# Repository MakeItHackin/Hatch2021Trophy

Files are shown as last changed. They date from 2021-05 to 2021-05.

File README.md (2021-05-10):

# Hatch2021Trophy
Overview of the trophies created for the HATCH 2021 Winners

Thanks for visiting this page to learn more about your HATCH trophy!

View my YouTube video for a quick overview and demo:
https://youtu.be/y4QBiJtTjaM

The trophy uses open source code and hardware, so please hack it to make it do what you want. It comes loaded with some demo code to test each of the components.

There may be updates to this page, but if you have any questions or comments, please initiate a "Issue" on github, and I will answer as soon as I can.

With the demo code loaded, the trophy will boot to the 'menu' screen.
Press the main button scroll through the menu.
When you go into the 'Demo Mode' Function, the program will loop forever. To exit the loop, just press the reset button.

The following functions are loaded with the demo software:
Lite Sense (view the analog signal from the light sensor. Minimum is ~888 (dark) and Maximum is ~1000 (very very bright))
Demo Mode (scrolls through all features, sensors, and animations)

The trophies feature the following major components:
ATTINY-85 Microcontroller
128x32 Pixel OLED display
Neopixel (WS2812v3) RGB LEDs
Light Sensor
18650 Battery, along with charging circuit (micro USB)
Pinout for all 8 pins on the microcontroller, so you can program it or add other features.

How to set up Arduino:
https://www.arduino.cc/en/Guide/ArduinoUno

How to Program the trophy (Arduino as ISP):
The trophy contains an ATTINY85 Microcontroller and can be programed unsing an arduino board, like the arduino uno.  
https://create.arduino.cc/projecthub/arjun/programming-attiny85-with-arduino-uno-afb829

Pinout for the ATTINY-85 eight-pin breakout:
-----------
| 1 2 3 4 |
| 5 6 7 8 |
-----------
PINs 1,2,3,5,6,7 are used for uploading code via ISCP to the ATTINY-85

1 - 
2 - 
3 - 
4 - 
5 - 
6 - 
7 - 
8 - 

It may be possible to program the trophy using a micro USB cable and the Micronucleus bootloader.  I have included the circuitry for that, but haven't tried to configure it.  It seems like most modern computers have trouble with it.  But if you want that functionality, give it a try!  For advanced users only.

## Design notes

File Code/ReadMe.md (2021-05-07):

The "HATCH2021TrophyCodeV1_0" is the main arduino program running the demo code.  The other files are the libraries needed for the RGB LEDs and OLED Display

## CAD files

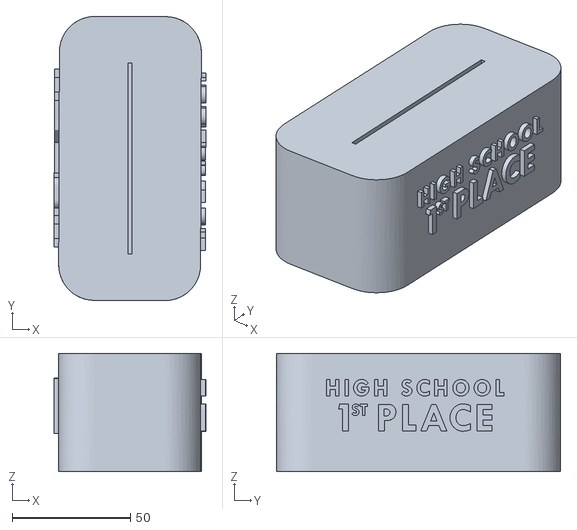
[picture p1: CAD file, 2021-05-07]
3DPrintedBases/Hatch2020TrophyBaseHS1st.stl
64.2 x 120.1 x 50.0

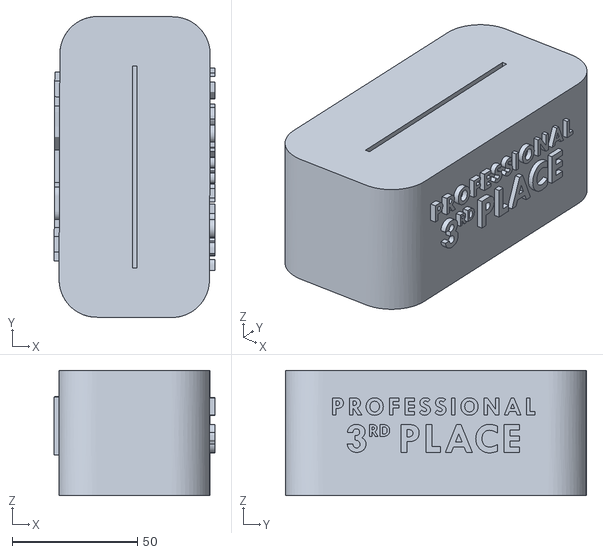
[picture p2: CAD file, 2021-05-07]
3DPrintedBases/Hatch2020TrophyBasePro3rd.stl
64.1 x 120.1 x 50.0

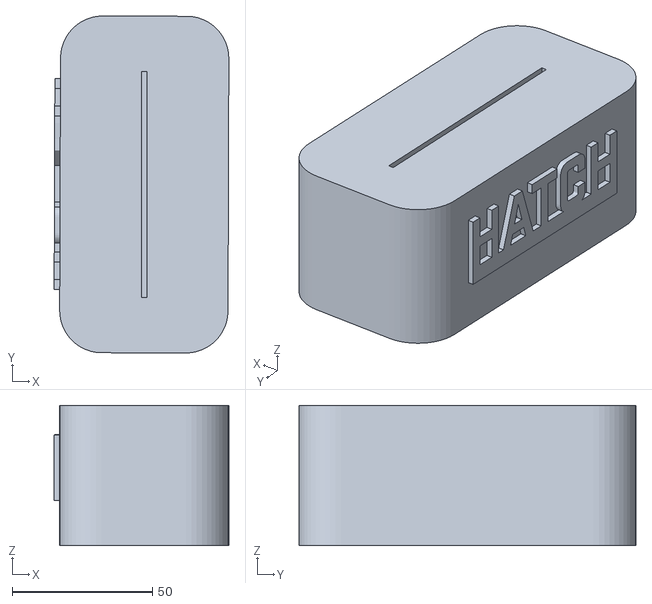
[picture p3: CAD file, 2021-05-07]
3DPrintedBases/Hatch2021TrophyBase.stl
62.3 x 120.1 x 50.0

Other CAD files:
3DPrintedBases/Hatch2020TrophyBaseHS2nd.stl
3DPrintedBases/Hatch2020TrophyBasePro2nd.stl
3DPrintedBases/Hatch2020TrophyBasePro1st.stl

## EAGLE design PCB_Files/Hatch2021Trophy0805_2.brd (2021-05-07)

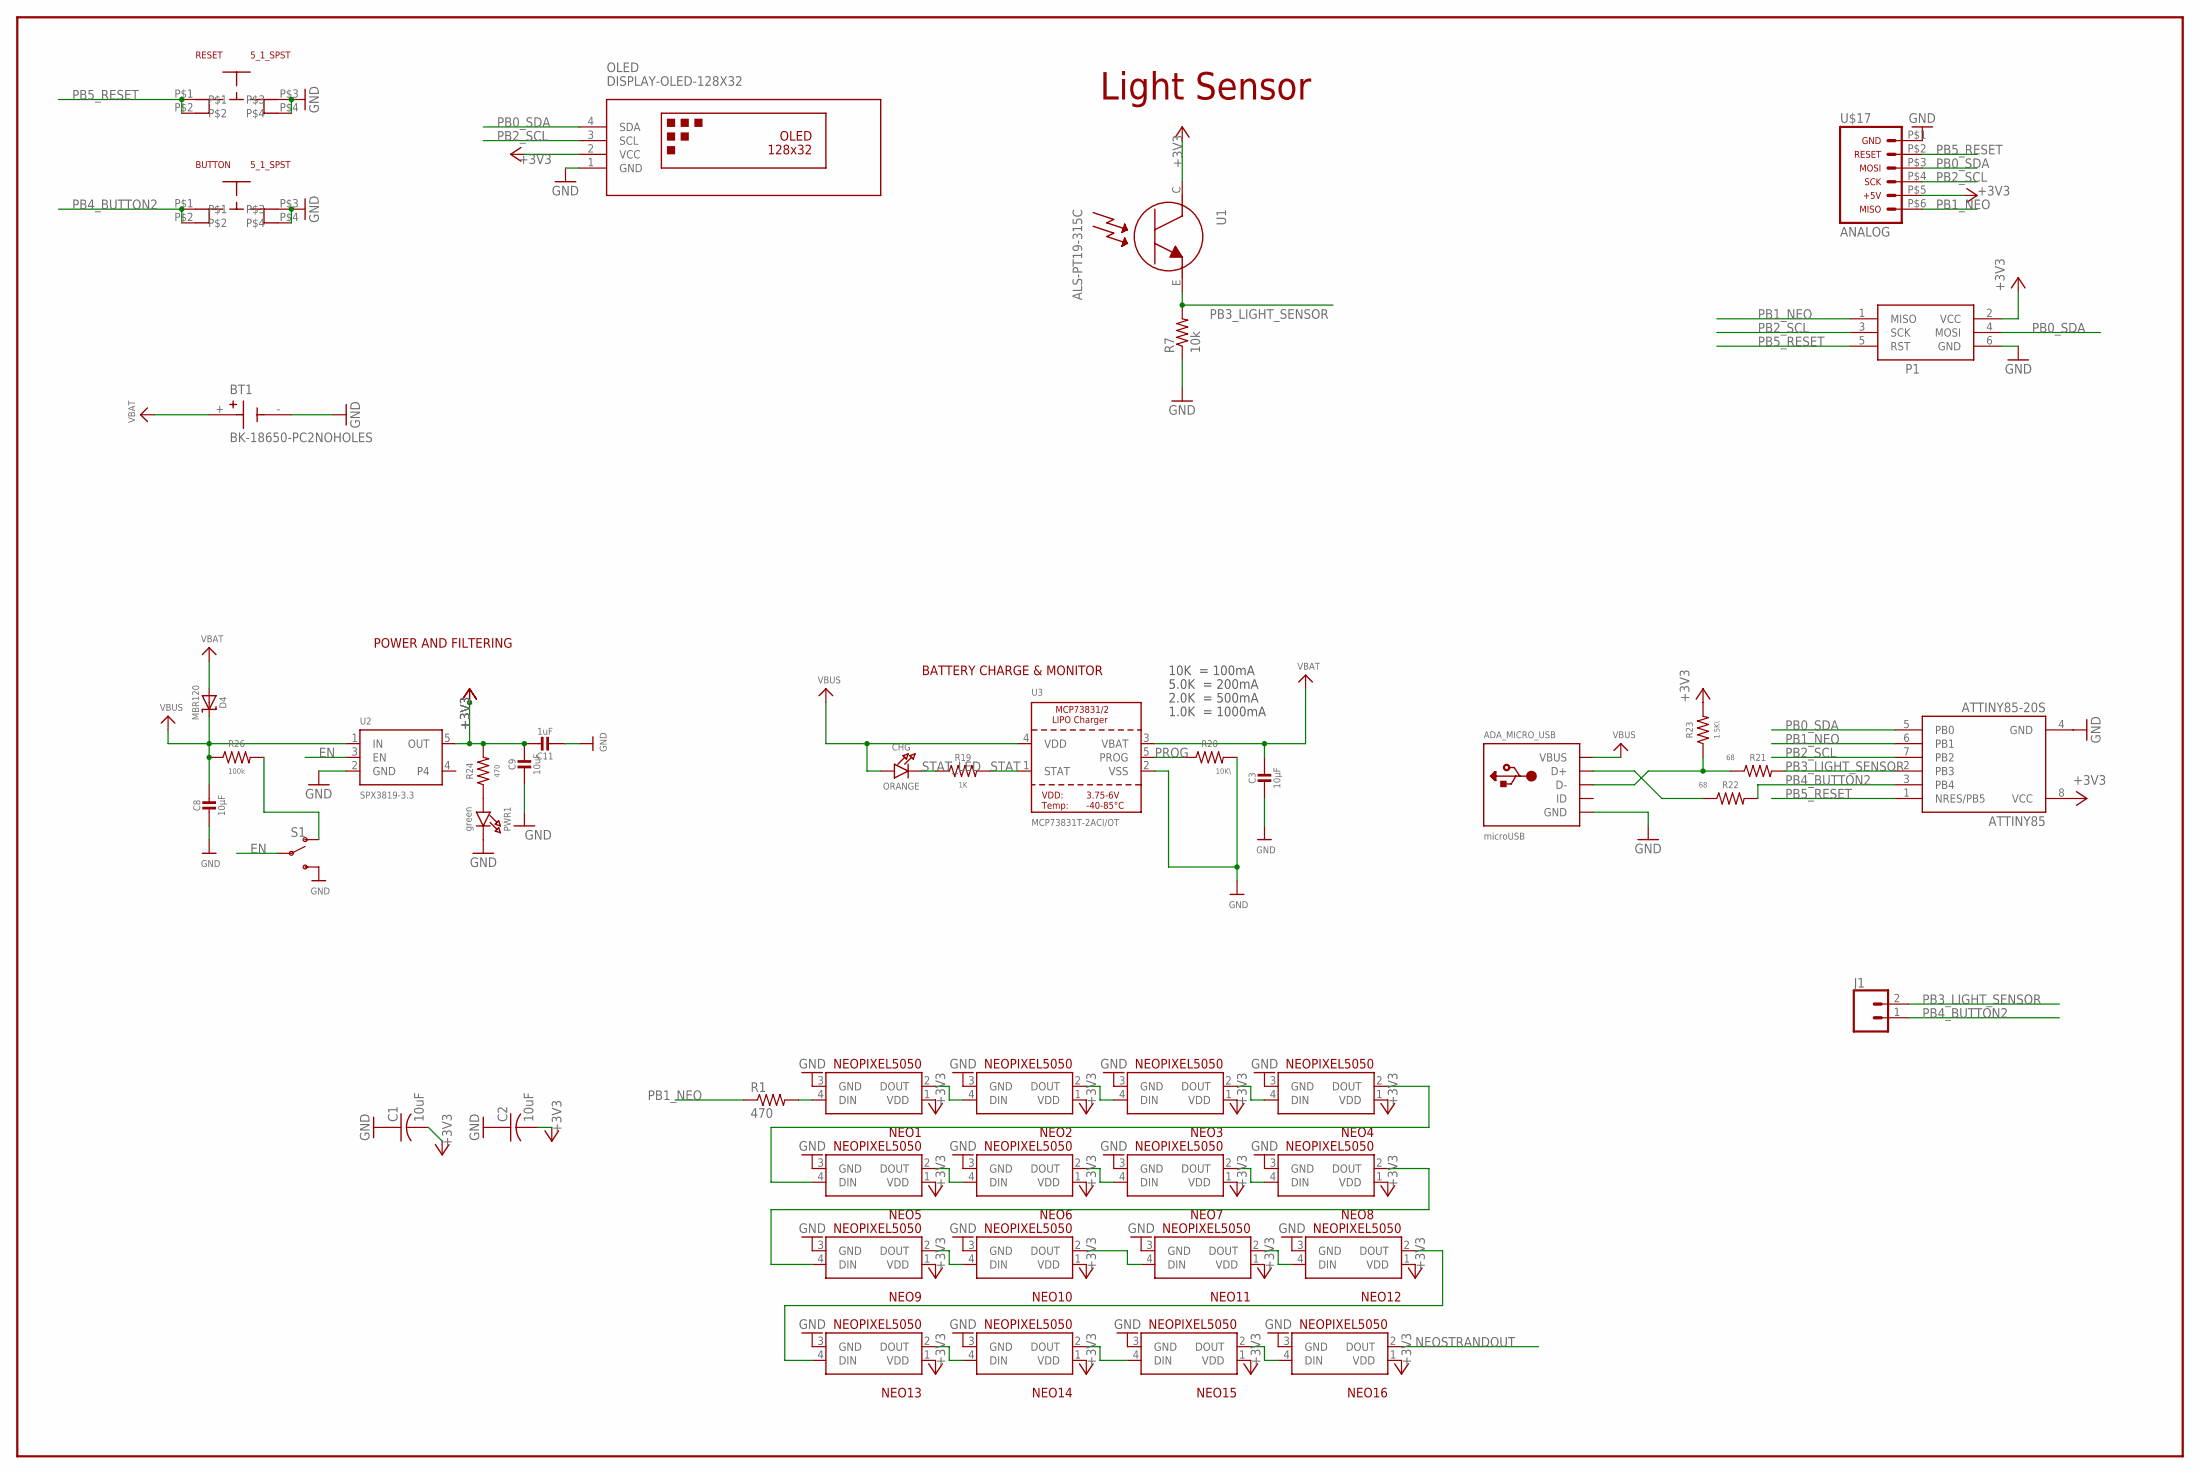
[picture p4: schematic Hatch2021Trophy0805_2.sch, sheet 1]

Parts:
ADA_MICRO_USB: microUSB; 4UCONN_20329_V2
ATTINY85: ATTINY85-20S; SOIC8_EIAJ_208MIL
BT1: BK-18650-PC2NOHOLES; BAT_BK-18650-PC2_NOHOLES
BUTTON: 5_1_SPST
C1, C2: 10uF; C0805
C3, C8: 10µF; 0805-NO@1
C9: 10uF; 0805-NO@1
C11: 1uF; 0805-NO@1
CHG: ORANGE; CHIPLED_0805_NOOUTLINE
D4: MBR120; SOD-123
J1: CONN_02; 1X02
NEO1, NEO2, NEO3, NEO4, NEO5, NEO6, NEO7, NEO8, NEO9, NEO10, NEO11, NEO12, NEO13, NEO14, NEO15, NEO16: NEOPIXEL5050
OLED: DISPLAY-OLED-128X32
P1: AVRISP-6; AVRISP
PWR1: green; CHIPLED_0805_NOOUTLINE
R1, R24: 470; R0805
R7: 10k; R0805
R19: 1K; R0805
R20: 10K\; R0805
R21, R22: 68; R0805
R23: 1.5K\; R0805
R26: 100k; R0805
RESET: 5_1_SPST
S1: SWITCH-SPDT-SMD-AYZ0202; SWITCH_DPDT_SMD_AYZ0202
U1: ALS-PT19-315C
U2: SPX3819-3.3; SOT23-5
U3: MCP73831T-2ACI/OT; SOT23-5
U$17: ICSP_FLATSMD_2X3; CONN-SMD-2X3

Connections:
+3V3: ATTINY85.8 (VCC), C1.2, C2.2, C9.1, C11.1, NEO1.1 (VDD), NEO2.1 (VDD), NEO3.1 (VDD), NEO4.1 (VDD), NEO5.1 (VDD), NEO6.1 (VDD), NEO7.1 (VDD), NEO8.1 (VDD), NEO9.1 (VDD), NEO10.1 (VDD), NEO11.1 (VDD), NEO12.1 (VDD), NEO13.1 (VDD), NEO14.1 (VDD), NEO15.1 (VDD), NEO16.1 (VDD), OLED.2 (VCC), P1.2 (VCC), R23.2, R24.2, U1.C, U2.5 (OUT), U$17.P$5 (5)
D+: ADA_MICRO_USB.D+, R22.1
D-: ADA_MICRO_USB.D-, R21.1, R23.1
EN: S1.2, U2.3 (EN)
GND: ADA_MICRO_USB.BASE@1 (GND), ADA_MICRO_USB.BASE@2 (GND), ADA_MICRO_USB.GND, ADA_MICRO_USB.SPRT@1 (GND), ADA_MICRO_USB.SPRT@2 (GND), ADA_MICRO_USB.SPRT@3 (GND), ADA_MICRO_USB.SPRT@4 (GND), ATTINY85.4 (GND), BT1.-, BUTTON.P$3, BUTTON.P$4, C1.1, C2.1, C3.2, C8.2, C9.2, C11.2, NEO1.3 (GND), NEO2.3 (GND), NEO3.3 (GND), NEO4.3 (GND), NEO5.3 (GND), NEO6.3 (GND), NEO7.3 (GND), NEO8.3 (GND), NEO9.3 (GND), NEO10.3 (GND), NEO11.3 (GND), NEO12.3 (GND), NEO13.3 (GND), NEO14.3 (GND), NEO15.3 (GND), NEO16.3 (GND), OLED.1 (GND), P1.6 (GND), PWR1.C, R7.1, R20.2, RESET.P$3, RESET.P$4, S1.3 (S), U2.2 (GND), U3.2 (VSS), U$17.P$1 (1)
unnamed: NEO13.2 (DOUT), NEO14.4 (DIN)
unnamed: NEO11.2 (DOUT), NEO12.4 (DIN)
unnamed: NEO12.2 (DOUT), NEO13.4 (DIN)
unnamed: NEO14.2 (DOUT), NEO15.4 (DIN)
unnamed: NEO15.2 (DOUT), NEO16.4 (DIN)
unnamed: NEO4.2 (DOUT), NEO5.4 (DIN)
unnamed: PWR1.A, R24.1
unnamed: R26.2, S1.1 (O)
unnamed: NEO1.4 (DIN), R1.2
unnamed: NEO8.2 (DOUT), NEO9.4 (DIN)
unnamed: NEO1.2 (DOUT), NEO2.4 (DIN)
unnamed: NEO2.2 (DOUT), NEO3.4 (DIN)
unnamed: NEO3.2 (DOUT), NEO4.4 (DIN)
unnamed: NEO5.2 (DOUT), NEO6.4 (DIN)
unnamed: NEO6.2 (DOUT), NEO7.4 (DIN)
unnamed: NEO7.2 (DOUT), NEO8.4 (DIN)
unnamed: NEO9.2 (DOUT), NEO10.4 (DIN)
unnamed: NEO10.2 (DOUT), NEO11.4 (DIN)
NEOSTRANDOUT: NEO16.2 (DOUT)
PB0_SDA: ATTINY85.5 (PB0), OLED.4 (SDA), P1.4 (MOSI), U$17.P$3 (3)
PB1_NEO: ATTINY85.6 (PB1), P1.1 (MISO), R1.1, U$17.P$6 (6)
PB2_SCL: ATTINY85.7 (PB2), OLED.3 (SCL), P1.3 (SCK), U$17.P$4 (4)
PB3_LIGHT_SENSOR: ATTINY85.2 (PB3), J1.2, R7.2, R21.2, U1.E
PB4_BUTTON2: ATTINY85.3 (PB4), BUTTON.P$1, BUTTON.P$2, J1.1, R22.2
PB5_RESET: ATTINY85.1 (NRES/PB5), P1.5 (RST), RESET.P$1, RESET.P$2, U$17.P$2 (2)
PROG: R20.1, U3.5 (PROG)
STAT: R19.2, U3.1 (STAT)
STAT_LED: CHG.C, R19.1
VBAT: BT1.+, C3.1, D4.A, U3.3 (VBAT)
VBUS: ADA_MICRO_USB.VBUS, C8.1, CHG.A, D4.C, R26.1, U2.1 (IN), U3.4 (VDD)

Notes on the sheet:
POWER AND FILTERING
10K = 100mA
5.0K = 200mA
2.0K = 500mA
1.0K = 1000mA
BATTERY CHARGE & MONITOR
Light Sensor

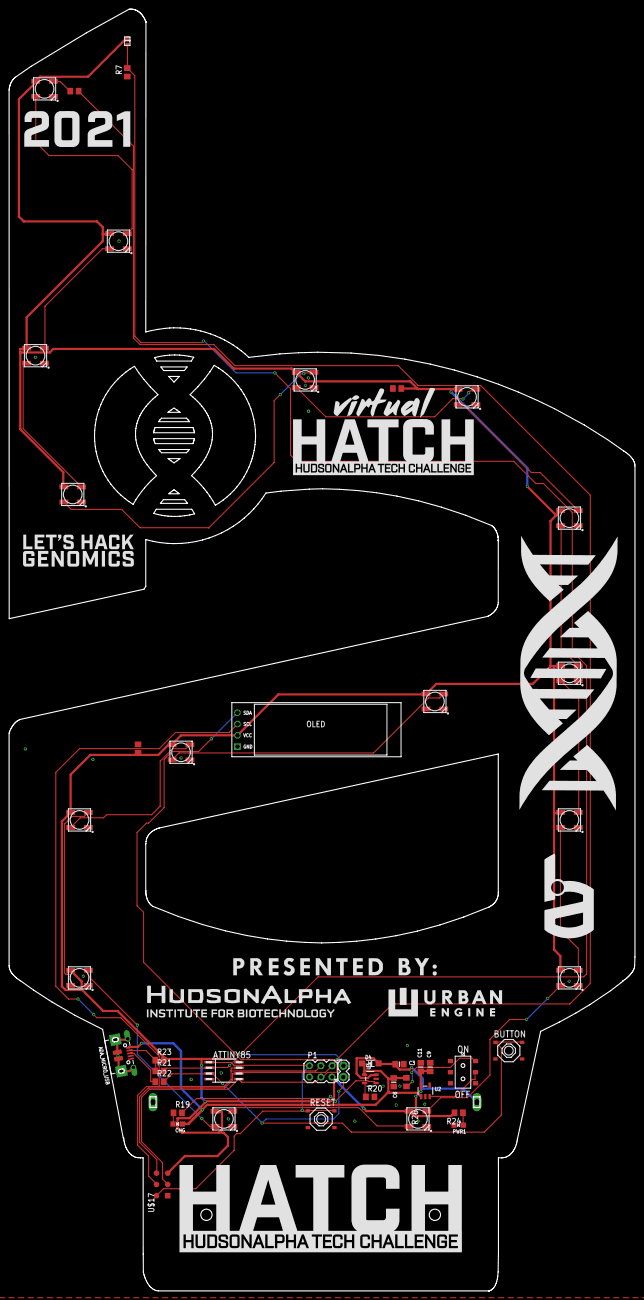
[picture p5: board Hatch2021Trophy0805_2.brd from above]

Board: 2 copper layers, 140.9 x 288.6 mm, 47 parts (1 on the bottom side), 34 nets.

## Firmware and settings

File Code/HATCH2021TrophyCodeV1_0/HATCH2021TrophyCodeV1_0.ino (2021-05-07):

//////////////////////////////////////////////////////////////////////////////////////////////////
//////////  2021 Hudson Alpha Tech Challenge - TROPHY DEMO CODE - BY ANDREW DENIO 
//////////////////////////////////////////////////////////////////////////////////////////////////


/* 
  IF YOU HAVE ANY QUESTIONS OR COMMENTS, FEEL FREE TO INITIATE AN ISSUE ON GITHUB.  I PLAN TO ADD ADDITIONAL COMMENTS IN THE CODE, AND MAYBE SOME MORE FEATURES!
  
  ALL LIBRARIES FOR COMPONENTS WILL BE INCLUDED IN GITHUB LINK, SO FEEL FREE TO TINKER AROUND!
  https://github.com/MakeItHackin/Hatch2021Trophy
 */


/*
  THIS CODE WAS USED TO DEMO THE BADGE FOR 2019 SPACE APPS CHALLENGE EVENT IN HUNTSVILLE.

  ALL LIBRARIES FOR COMPONENTS WILL BE INCLUDED IN GITHUB LINK, SO FEEL FREE TO TINKER AROUND!
  https://github.com/ExpeditionSTEM/2019SpaceAppsBadge

  LIBRARIES FOR NEOPIXELS WERE DERIVED FROM LIBRARIES BY ADAFRUIT

  Adafruit invests time and resources providing this open source code,
  please support Adafruit and open-source hardware by purchasing
  products from Adafruit!
  Written by Limor Fried/Ladyada for Adafruit Industries.
  MIT license, all text above must be included in any redistribution
  
 */


////////////////////////////////////////////////////////////////
//////////  ATTINY 85 PINOUT
////////////////////////////////////////////////////////////////

 
/*
  
  GND - BATTERY NEGATIVE TERMINAL
  VCC - BATTERY POSITIVE TERMINAL
  PBO - I2C BUS - SDA
  PB1 - NEOPIXEL OUT
  PB2 - I2C BUS - SCL
  PB3 - LIGHT SENSOR INPUT
  PB4 - BUTTON INPUT
  PB5 - RESET BUTTON
  
 */


////////////////////////////////////////////////////////////////
//////////  VARIABLES AND LIBRARIES
////////////////////////////////////////////////////////////////

#include "TinyWireM.h" // USED FOR I2C CAPABILITIES
#include "TinyOzOLED.h" // USED FOR THE SSD1306 OLED SCREEN

#include <tinyNeoPixel_Static.h>  // USED FOR NEOPIXELS
#define PIN 1
// Parameter 1 = number of pixels in strip
// Parameter 2 = Arduino pin number (most are valid)
// Parameter 3 = pixel type flags, add together as needed:
//   NEO_GRB     Pixels are wired for GRB bitstream (most NeoPixel products)
//   NEO_RGB     Pixels are wired for RGB bitstream (v1 FLORA pixels, not v2)
// Parameter 4 = array to store pixel data in      
#define NUMPIXELS 16
// Since this is for the static version of the library, we need to supply the pixel array
// This saves space by eliminating use of malloc() and free(), and makes the RAM used for
// the frame buffer show up when the sketch is compiled.
byte pixels[NUMPIXELS * 3];
// When we setup the NeoPixel library, we tell it how many pixels, and which pin to use to send signals.
// Note that for older NeoPixel strips you might need to change the third parameter--see the strandtest
// example for more information on possible values. Finally, for the 4th argument we pass the array we
// defined above.
tinyNeoPixel strip = tinyNeoPixel(NUMPIXELS, PIN, NEO_GRB, pixels);
// IMPORTANT: To reduce NeoPixel burnout risk, add 1000 uF capacitor across
// pixel power leads, add 300 - 500 Ohm resistor on first pixel's data input
// and minimize distance between Arduino and first pixel.  Avoid connecting
// on a live circuit...if you must, connect GND first.


#define BUTTON_PIN   4    // Digital IO pin connected to the button.  This will be
                          // driven with a pull-up resistor so the switch should
                          // pull the pin to ground momentarily.  On a high -> low
                          // transition the button press logic will execute.

                          

#define LIGHT_SENSOR_PIN A3  // THIS IS PB3, BUT MUST LABEL IT A3 IN ORDER FOR THE ANALOG FUNCTIONS TO WORK
int lightSensorValue = 0;






const unsigned char HudsonAlphaBitmap [] PROGMEM = {
  0x00, 0x00, 0xc0, 0xc0, 0x80, 0x00, 0x00, 0x00, 0x00, 0x00, 0x00, 0xc0, 0xc0, 0x00, 0x00, 0x00, 
  0x00, 0x00, 0x00, 0x00, 0x00, 0x00, 0x00, 0x00, 0x00, 0x00, 0x00, 0x00, 0x00, 0x00, 0x00, 0x00, 
  0x00, 0x00, 0x00, 0x00, 0x00, 0x00, 0x00, 0x00, 0x00, 0x00, 0x00, 0x00, 0x00, 0x00, 0x00, 0x00, 
  0x00, 0x00, 0x00, 0x00, 0x00, 0x00, 0x00, 0x00, 0x00, 0x00, 0x00, 0x00, 0x00, 0x00, 0x00, 0x00, 
  0x00, 0x00, 0x00, 0x00, 0x00, 0x00, 0x00, 0x00, 0x00, 0x00, 0x00, 0x00, 0x80, 0xc0, 0xc0, 0x80, 
  0x00, 0x00, 0x00, 0x00, 0x00, 0x00, 0x00, 0x00, 0x00, 0x00, 0x00, 0x00, 0x00, 0x00, 0x00, 0x00, 
  0x00, 0x00, 0x00, 0x00, 0x00, 0x00, 0x00, 0x00, 0x00, 0x00, 0x00, 0x00, 0x00, 0x00, 0x00, 0x00, 
  0x00, 0x00, 0x00, 0x00, 0x00, 0x00, 0x00, 0x00, 0x00, 0x00, 0x00, 0x00, 0x00, 0x00, 0x00, 0x00, 
  0x00, 0x00, 0xff, 0xff, 0xff, 0x0c, 0x0c, 0x0c, 0x0c, 0x0c, 0x0c, 0xff, 0xff, 0x00, 0x00, 0x00, 
  0xff, 0xff, 0xc0, 0x80, 0x80, 0x80, 0xfe, 0xff, 0x7f, 0x00, 0x00, 0xff, 0xff, 0xc3, 0x83, 0x83, 
  0x83, 0xc3, 0xff, 0xfe, 0x00, 0x00, 0xc4, 0xce, 0x9f, 0x9b, 0x9b, 0x93, 0xf3, 0xf3, 0x72, 0x00, 
  0x00, 0x7c, 0xfe, 0xc7, 0x83, 0x83, 0x83, 0x83, 0xff, 0xfe, 0x7c, 0x00, 0x00, 0xff, 0xff, 0x0e, 
  0x1c, 0x38, 0x78, 0x70, 0xff, 0xff, 0x00, 0x00, 0xc0, 0xf0, 0x78, 0x3e, 0x3f, 0x33, 0x33, 0x3f, 
  0x3e, 0x78, 0xf0, 0xc0, 0x00, 0x00, 0xff, 0xff, 0x80, 0x80, 0x80, 0x80, 0x80, 0x00, 0x00, 0xff, 
  0xff, 0x33, 0x33, 0x33, 0x33, 0x1f, 0x0e, 0x00, 0x00, 0xff, 0xff, 0x18, 0x18, 0x18, 0x18, 0x18, 
  0xff, 0xff, 0x00, 0x00, 0xc0, 0xf0, 0x78, 0x7e, 0x6f, 0x6f, 0x7e, 0x78, 0xe0, 0xc0, 0x00, 0x00, 
  0x00, 0x00, 0xf0, 0x00, 0xf0, 0x60, 0xc0, 0xe0, 0xe0, 0x20, 0x70, 0x50, 0xd0, 0x00, 0x10, 0xf0, 
  0x10, 0x10, 0x00, 0xf0, 0x01, 0x10, 0xf0, 0x10, 0x10, 0xe0, 0x80, 0x00, 0x80, 0xe0, 0x10, 0x10, 
  0xf0, 0x10, 0x00, 0xf0, 0x50, 0x50, 0x50, 0x00, 0x00, 0xf0, 0x51, 0x50, 0x50, 0xe0, 0xf0, 0x10, 
  0x30, 0xe0, 0xe0, 0xf0, 0xd0, 0xf1, 0x61, 0x00, 0x00, 0xf0, 0x50, 0x50, 0xf0, 0x00, 0xf0, 0x00, 
  0xe0, 0x30, 0x10, 0xf0, 0xe0, 0x10, 0xf0, 0x10, 0x10, 0x00, 0xf0, 0x50, 0x50, 0x00, 0xe0, 0x10, 
  0x10, 0x10, 0x00, 0xf0, 0x40, 0x40, 0xf0, 0x00, 0xf0, 0x60, 0xc0, 0xf0, 0x00, 0xe0, 0x10, 0x11, 
  0xf0, 0x00, 0xf0, 0x00, 0x00, 0x00, 0xe0, 0x10, 0x10, 0xf0, 0x00, 0xe0, 0x10, 0x50, 0xd0, 0x00, 
  0x30, 0x60, 0xe0, 0x30, 0x00, 0x00, 0x00, 0x00, 0x00, 0x00, 0x00, 0x00, 0x00, 0x00, 0x00, 0x00, 
  0x00, 0x00, 0x01, 0x00, 0x01, 0x00, 0x00, 0x01, 0x00, 0x01, 0x01, 0x01, 0x01, 0x00, 0x00, 0x01, 
  0x00, 0x00, 0x00, 0x01, 0x00, 0x00, 0x01, 0x00, 0x00, 0x00, 0x01, 0x01, 0x01, 0x00, 0x00, 0x00, 
  0x01, 0x00, 0x00, 0x01, 0x01, 0x01, 0x01, 0x00, 0x00, 0x01, 0x00, 0x00, 0x00, 0x00, 0x01, 0x01, 
  0x01, 0x00, 0x00, 0x00, 0x00, 0x01, 0x01, 0x00, 0x00, 0x01, 0x01, 0x01, 0x01, 0x00, 0x01, 0x00, 
  0x00, 0x01, 0x01, 0x01, 0x00, 0x00, 0x01, 0x00, 0x00, 0x00, 0x01, 0x01, 0x01, 0x00, 0x01, 0x01, 
  0x01, 0x01, 0x00, 0x01, 0x00, 0x00, 0x01, 0x00, 0x01, 0x00, 0x00, 0x01, 0x00, 0x01, 0x01, 0x01, 
  0x01, 0x00, 0x01, 0x01, 0x01, 0x01, 0x00, 0x01, 0x01, 0x01, 0x00, 0x00, 0x01, 0x01, 0x01, 0x00, 
  0x00, 0x00, 0x01, 0x00, 0x00, 0x00, 0x00, 0x00, 0x00, 0x00, 0x00, 0x00, 0x00, 0x00, 0x00, 0x00
};


// 'hatch2020', 128x32px
const unsigned char HATCH2020Bitmap [] PROGMEM = {
  0x00, 0x00, 0x00, 0x00, 0x00, 0x00, 0x00, 0x00, 0x00, 0x00, 0x00, 0x00, 0x00, 0x00, 0x00, 0x00, 
  0xfe, 0xfe, 0xfe, 0xfe, 0xfe, 0x00, 0x00, 0x00, 0x00, 0x00, 0x00, 0x00, 0xfe, 0xfe, 0xfe, 0xfe, 
  0xfe, 0x00, 0x00, 0x00, 0x00, 0x00, 0x00, 0x00, 0x00, 0x80, 0xf0, 0xfe, 0xfe, 0xfe, 0xfe, 0xfe, 
  0xfe, 0xf8, 0xc0, 0x00, 0x00, 0x00, 0x00, 0x1e, 0x3e, 0x3e, 0x3e, 0x3e, 0x3e, 0xfe, 0xfe, 0xfe, 
  0xfe, 0xfe, 0x3e, 0x3e, 0x3e, 0x3e, 0x3e, 0x3e, 0x00, 0x00, 0xf0, 0xfc, 0xfc, 0xfe, 0xfe, 0x3e, 
  0x1e, 0x1e, 0x1e, 0x1e, 0x1e, 0x3e, 0xfe, 0xfe, 0xfe, 0xfc, 0xf0, 0x00, 0x00, 0x00, 0x00, 0xfe, 
  0xfe, 0xfe, 0xfe, 0xfe, 0x00, 0x00, 0x00, 0x00, 0x00, 0x00, 0x00, 0xfe, 0xfe, 0xfe, 0xfe, 0xfe, 
  0x00, 0x00, 0x00, 0x00, 0x00, 0x00, 0x00, 0x00, 0x00, 0x00, 0x00, 0x00, 0x00, 0x00, 0x00, 0x00, 
  0x00, 0x00, 0x00, 0x00, 0x00, 0x00, 0x00, 0x00, 0x00, 0x00, 0x00, 0x00, 0x00, 0x00, 0x00, 0x00, 
  0xff, 0xff, 0xff, 0xff, 0xff, 0x7c, 0x7c, 0x7c, 0x7c, 0x7c, 0x7c, 0x7c, 0xff, 0xff, 0xff, 0xff, 
  0xff, 0x00, 0x00, 0x00, 0x00, 0x00, 0x00, 0xe0, 0xfc, 0xff, 0xff, 0xff, 0x8f, 0x81, 0x80, 0x87, 
  0xff, 0xff, 0xff, 0xfe, 0xf0, 0x80, 0x00, 0x00, 0x00, 0x00, 0x00, 0x00, 0x00, 0xff, 0xff, 0xff, 
  0xff, 0xff, 0x00, 0x00, 0x00, 0x00, 0x00, 0x00, 0x00, 0x00, 0xff, 0xff, 0xff, 0xff, 0xff, 0x00, 
  0x00, 0x00, 0x00, 0x00, 0x00, 0x00, 0x01, 0x01, 0x01, 0x01, 0x01, 0x00, 0x00, 0x00, 0x00, 0xff, 
  0xff, 0xff, 0xff, 0xff, 0x7c, 0x7c, 0x7c, 0x7c, 0x7c, 0x7c, 0x7c, 0xff, 0xff, 0xff, 0xff, 0xff, 
  0x00, 0x00, 0x00, 0x00, 0x00, 0x00, 0x00, 0x00, 0x00, 0x00, 0x00, 0x00, 0x00, 0x00, 0x00, 0x00, 
  0x00, 0x00, 0x00, 0x00, 0x00, 0x00, 0x00, 0x00, 0x00, 0x00, 0x00, 0x00, 0x00, 0x00, 0x00, 0x00, 
  0xff, 0xff, 0xff, 0xff, 0xff, 0x00, 0x00, 0x00, 0x00, 0x00, 0x00, 0x00, 0xff, 0xff, 0xff, 0xff, 
  0xff, 0x80, 0x00, 0x00, 0x80, 0xf0, 0xfe, 0xff, 0xff, 0xff, 0x07, 0x07, 0x07, 0x07, 0x07, 0x07, 
  0x07, 0x07, 0x3f, 0xff, 0xff, 0xff, 0xfc, 0xe0, 0x00, 0x00, 0x00, 0x00, 0x00, 0xff, 0xff, 0xff, 
  0xff, 0xff, 0x80, 0x00, 0x00, 0x00, 0x00, 0x00, 0x00, 0x00, 0x1f, 0xff, 0xff, 0xff, 0xff, 0xf0, 
  0xf0, 0xf0, 0xf0, 0xf0, 0xf0, 0xf0, 0xff, 0xff, 0xff, 0xff, 0x3f, 0x00, 0x00, 0x00, 0x80, 0xff, 
  0xff, 0xff, 0xff, 0xff, 0x00, 0x00, 0x00, 0x00, 0x00, 0x00, 0x00, 0xff, 0xff, 0xff, 0xff, 0xff, 
  0x00, 0x00, 0x00, 0x00, 0x00, 0x00, 0x00, 0x00, 0x00, 0x00, 0x00, 0x00, 0x00, 0x00, 0x00, 0x00, 
  0x00, 0x00, 0x00, 0x00, 0x00, 0x00, 0x00, 0x00, 0x00, 0x00, 0x00, 0x00, 0x00, 0x00, 0x00, 0x00, 
  0x7f, 0x7f, 0x7f, 0x7f, 0x7f, 0x7f, 0x7f, 0x7f, 0x7f, 0x7f, 0x7f, 0x7f, 0x7f, 0x7f, 0x7f, 0x7f, 
  0x7f, 0x7f, 0x7f, 0x7f, 0x7f, 0x7f, 0x7f, 0x7f, 0x7f, 0x7f, 0x7f, 0x7f, 0x7f, 0x7f, 0x7f, 0x7f, 
  0x7f, 0x7f, 0x7f, 0x7f, 0x7f, 0x7f, 0x7f, 0x7f, 0x7f, 0x7f, 0x7f, 0x7f, 0x7f, 0x7f, 0x7f, 0x7f, 
  0x7f, 0x7f, 0x7f, 0x7f, 0x7f, 0x7f, 0x7f, 0x7f, 0x7f, 0x7f, 0x7f, 0x7f, 0x7f, 0x7f, 0x7f, 0x7f, 
  0x7f, 0x7f, 0x7f, 0x7f, 0x7f, 0x7f, 0x7f, 0x7f, 0x7f, 0x7f, 0x7f, 0x7f, 0x7f, 0x7f, 0x7f, 0x7f, 
  0x7f, 0x7f, 0x7f, 0x7f, 0x7f, 0x7f, 0x7f, 0x7f, 0x7f, 0x7f, 0x7f, 0x7f, 0x7f, 0x7f, 0x7f, 0x7f, 
  0x00, 0x00, 0x00, 0x00, 0x00, 0x00, 0x00, 0x00, 0x00, 0x00, 0x00, 0x00, 0x00, 0x00, 0x00, 0x00
};


// 'urbanengine', 128x32px
const unsigned char UrbanEngineBitmap [] PROGMEM = {
  0x00, 0x00, 0x00, 0x00, 0xf8, 0xf8, 0xf8, 0xf8, 0xf8, 0xf8, 0xf8, 0x00, 0x00, 0x00, 0x00, 0x00, 
  0xfe, 0xfe, 0xfe, 0xfe, 0xfe, 0xfe, 0xfe, 0x00, 0x00, 0x00, 0x00, 0x00, 0xf8, 0xf8, 0xf8, 0xf8, 
  0xf8, 0xf8, 0xf8, 0x00, 0x00, 0x00, 0x00, 0x00, 0x00, 0x00, 0xf8, 0xf8, 0xf8, 0xf0, 0x00, 0x00, 
  0x00, 0x00, 0x00, 0xf8, 0xf8, 0xf8, 0x00, 0x00, 0x00, 0x00, 0x00, 0x00, 0x00, 0xf0, 0xf8, 0xf8, 
  0xf8, 0x38, 0x38, 0x78, 0xf0, 0xf0, 0xe0, 0x80, 0x00, 0x00, 0x00, 0x00, 0x00, 0x00, 0x00, 0xf8, 
  0xf8, 0xf8, 0x38, 0x38, 0x78, 0xf0, 0xf0, 0xe0, 0x00, 0x00, 0x00, 0x00, 0x00, 0x00, 0x00, 0x00, 
  0x00, 0xc0, 0xf0, 0xf8, 0xf8, 0xf8, 0xf0, 0x80, 0x00, 0x00, 0x00, 0x00, 0x00, 0x00, 0x00, 0x00, 
  0xf0, 0xf8, 0xf8, 0xf0, 0xe0, 0xc0, 0x00, 0x00, 0x00, 0x00, 0xf8, 0xf8, 0xf8, 0x00, 0x00, 0x00, 
  0x00, 0x00, 0x00, 0x00, 0xff, 0xff, 0xff, 0xff, 0xff, 0xff, 0xff, 0x00, 0x00, 0x00, 0x00, 0x00, 
  0xff, 0xff, 0xff, 0xff, 0xff, 0xff, 0xff, 0x00, 0x00, 0x00, 0x00, 0x00, 0xff, 0xff, 0xff, 0xff, 
  0xff, 0xff, 0xff, 0x00, 0x00, 0x00, 0x00, 0x00, 0x00, 0x00, 0x7f, 0xff, 0xff, 0xff, 0x80, 0x80, 
  0x80, 0x80, 0xc0, 0xff, 0xff, 0x7f, 0x00, 0x00, 0x00, 0x00, 0x00, 0x00, 0x00, 0xff, 0xff, 0xff, 
  0xff, 0x1e, 0x7e, 0xfe, 0xff, 0xef, 0x87, 0x01, 0x00, 0x00, 0x00, 0x00, 0x00, 0x00, 0x00, 0xff, 
  0xff, 0xff, 0x8e, 0x8e, 0x8e, 0xdf, 0xff, 0xff, 0xf8, 0x00, 0x00, 0x00, 0x00, 0x00, 0xc0, 0xf8, 
  0xfe, 0x7f, 0x7f, 0x73, 0x71, 0x73, 0x7f, 0x7f, 0xfe, 0xf8, 0xe0, 0x00, 0x00, 0x00, 0x00, 0x00, 
  0xff, 0xff, 0xff, 0xff, 0x07, 0x0f, 0x1f, 0x7e, 0xf8, 0xf8, 0xff, 0xff, 0xff, 0x00, 0x00, 0x00, 
  0x00, 0x00, 0x00, 0x00, 0xff, 0xff, 0xff, 0xff, 0xff, 0xff, 0xff, 0x80, 0x80, 0x80, 0x80, 0x80, 
  0x87, 0x87, 0x87, 0x87, 0x87, 0x87, 0x87, 0x80, 0x80, 0x80, 0x80, 0x80, 0xff, 0xff, 0xff, 0xff, 
  0xff, 0xff, 0xff, 0x00, 0x00, 0x00, 0x00, 0x00, 0x00, 0x00, 0x00, 0x00, 0x01, 0x03, 0x03, 0x03, 
  0x83, 0xc3, 0xc3, 0xc1, 0xc1, 0xc0, 0x00, 0x00, 0x00, 0x00, 0x00, 0x00, 0x00, 0xc3, 0xc3, 0x83, 
  0x03, 0x00, 0xc0, 0xc0, 0x03, 0x03, 0x03, 0x03, 0x02, 0x00, 0x00, 0x00, 0x80, 0x80, 0xc0, 0xc3, 
  0xc3, 0x83, 0x03, 0x03, 0x03, 0x03, 0x03, 0x01, 0x00, 0xc0, 0xc0, 0x00, 0x00, 0x03, 0x03, 0x03, 
  0x03, 0x00, 0xc0, 0xc0, 0x80, 0x00, 0x00, 0xc0, 0xc1, 0x03, 0x03, 0x03, 0x00, 0x00, 0x00, 0x00, 
  0xc3, 0xc3, 0xc3, 0xc3, 0xc0, 0x80, 0x00, 0x00, 0x00, 0x03, 0x03, 0x03, 0x03, 0x00, 0x00, 0x00, 
  0x00, 0x00, 0x00, 0x00, 0x7f, 0x7f, 0x7f, 0x7f, 0x7f, 0x7f, 0x7f, 0x7f, 0x7f, 0x7f, 0x7f, 0x7f, 
  0x7f, 0x7f, 0x7f, 0x7f, 0x7f, 0x7f, 0x7f, 0x7f, 0x7f, 0x7f, 0x7f, 0x7f, 0x7f, 0x7f, 0x7f, 0x7f, 
  0x7f, 0x7f, 0x7f, 0x00, 0x00, 0x00, 0x00, 0x00, 0x00, 0x00, 0x00, 0x00, 0x00, 0x00, 0x00, 0x00, 
  0x7f, 0x7f, 0x7f, 0x66, 0x66, 0x66, 0x00, 0x00, 0x00, 0x00, 0x00, 0x00, 0x00, 0x7f, 0x7f, 0x07, 
  0x0e, 0x3c, 0x7f, 0x7f, 0x00, 0x00, 0x00, 0x00, 0x00, 0x00, 0x0e, 0x3f, 0x3f, 0x71, 0x60, 0x6c, 
  0x7d, 0x3d, 0x3c, 0x00, 0x00, 0x00, 0x00, 0x00, 0x00, 0x7f, 0x7f, 0x00, 0x00, 0x00, 0x00, 0x00, 
  0x00, 0x00, 0x7f, 0x7f, 0x07, 0x1e, 0x3c, 0x7f, 0x7f, 0x00, 0x00, 0x00, 0x00, 0x00, 0x00, 0x00, 
  0x7f, 0x7f, 0x6e, 0x66, 0x66, 0x64, 0x00, 0x00, 0x00, 0x00, 0x00, 0x00, 0x00, 0x00, 0x00, 0x00
};

// MENU VARIABLES
int NewMenuVar = 1;
int MenuCount = 3;
int OldMenuVar = MenuCount + 1; 

// BUTTON VARIABLES
bool newState;
bool oldState = HIGH;

/*
AWARD TYPE:
0 - DEMO MODE
1 - HIGH SCHOOL FIRST PLACE
2 - HIGH SCHOOL SECOND PLACE
3 - PROFESSIONAL FIRST PLACE
4 - PROFESSIONAL SECOND PLACE
5 - PROFESSIONAL THIRD PLACE
6 - HUDSON ALPHA
7 - URBAN ENGINE
8 - HATCH
*/
int awardtype = 8; //CHAGE THIS VALUE TO CHANGE THE AWARD TYPE


////////////////////////////////////////////////////////////////
//////////  SETUP LOOP
////////////////////////////////////////////////////////////////

void setup() {

  //Initialize pins
  pinMode(BUTTON_PIN, INPUT_PULLUP);
  pinMode(LIGHT_SENSOR_PIN, INPUT);
  pinMode(PIN,OUTPUT); //set pin output - this is not done internally by the library for Static version of library

  //Start Neopixels
  //strip.begin(); //Static version does not use this.
  strip.show(); // Initialize all pixels to 'off'

  //Start Screen.  Some of these settings are to get the screen in the right orientation.
  OzOled.init();                 
  OzOled.clearDisplay(); 
  OzOled.setNormalDisplay();  
  OzOled.sendCommand(0xA1);
  OzOled.sendCommand(0xC8);
  OzOled.setHorizontalMode(); 
  OzOled.setBrightness(255);    

  //Draw the SPACE APPS logo
  OzOled.drawBitmap(HATCH2020Bitmap, 0, 0, 16, 8);

  delay(500);

  OzOled.drawBitmap(HudsonAlphaBitmap, 0, 0, 16, 8);

  delay(500);
    OzOled.drawBitmap(UrbanEngineBitmap, 0, 0, 16, 8);

   
  delay(500);

  goToAwardMenu();

  delay(1000);
  
  OzOled.clearDisplay();  

  
}


////////////////////////////////////////////////////////////////
//////////  MAIN LOOP
////////////////////////////////////////////////////////////////

void loop() {

  // Check the button for activity
  DoButton();

  // Change the menu if button has been pushed
  MenuChange();

  //Reinitialize menu variables
  OldMenuVar = NewMenuVar;

}


////////////////////////////////////////////////////////////////
//////////  OTHER FUNCTIONS
////////////////////////////////////////////////////////////////

  
///////////////////////////////////////////////////////////////////////////////////////////////////////////////////

void goToAwardMenu(){
 
  OzOled.clearDisplay();

  if (awardtype == 0){
    //DEMO MODE
    OzOled.setCursorXY(0,1);   
    OzOled.printString("    DEVELOPER ");  
    OzOled.setCursorXY(0,3);  
    OzOled.printString("   SECRET MODE ");  
  }
  else if (awardtype == 1){
    //HIGH SCHOOL FIRST PLACE
    OzOled.setCursorXY(0,0);   
    OzOled.printString("   HIGH SCHOOL ");  
    OzOled.setCursorXY(0,2);  
    OzOled.printString("    1st PLACE ");  
              
  }
  else if (awardtype == 2){
    //HIGH SCHOOL SECOND PLACE
    OzOled.setCursorXY(0,0);   
    OzOled.printString("   HIGH SCHOOL ");  
    OzOled.setCursorXY(0,2);  
    OzOled.printString("    2nd PLACE ");  
  }
  else if (awardtype == 3){
    //PROFESSIONAL FIRST PLACE
    OzOled.setCursorXY(0,0);   
    OzOled.printString("   PROFESSIONAL ");  
    OzOled.setCursorXY(0,2);  
    OzOled.printString("    1st PLACE ");  
  }
  else if (awardtype == 4){
    //PROFESSIONAL SECOND PLACE
    OzOled.setCursorXY(0,0);   
    OzOled.printString("   PROFESSIONAL ");  
    OzOled.setCursorXY(0,2);  
    OzOled.printString("    2nd PLACE ");  
  }
  else if (awardtype == 5){
    //PROFESSIONAL THIRD PLACE
    OzOled.setCursorXY(0,0);   
    OzOled.printString("   PROFESSIONAL ");  
    OzOled.setCursorXY(0,2);  
    OzOled.printString("    3rd PLACE ");  
  }
  else if (awardtype == 6){
    //HUDSON ALPHA
    OzOled.drawBitmap(HudsonAlphaBitmap, 0, 0, 16, 8);
  }
  else if (awardtype == 7){
    //URBAN ENGINE
    OzOled.drawBitmap(UrbanEngineBitmap, 0, 0, 16, 8);
  }  
  else if (awardtype == 8){
    //HATCH
    OzOled.drawBitmap(HATCH2020Bitmap, 0, 0, 16, 8);
  }
  else {
    //do nothing
    //PLACE HOLDER
  }
        
}

///////////////////////////////////////////////////////////////////////////////////////////////////////////////////

void DoButton(){

    // Get current button state.
  newState = digitalRead(BUTTON_PIN);

  // Check if state changed from high to low (button press).
  if (newState == LOW && oldState == HIGH) {
    // Short delay to debounce button.
    delay(20);
    // Check if button is still low after debounce.
    newState = digitalRead(BUTTON_PIN);
    if (newState == LOW) {
      NewMenuVar = OldMenuVar + 1;
      OzOled.clearDisplay();  
    }
    else {
      NewMenuVar = OldMenuVar;
    }
    if (NewMenuVar == MenuCount+1) {
       NewMenuVar = 1;
       }      
  }

  // Set the last button state to the old state.
  oldState = newState;

}

///////////////////////////////////////////////////////////////////////////////////////////////////////////////////

void MenuChange() {
  
         if (NewMenuVar == MenuCount+1) {
              NewMenuVar = 1;
             }
         
         if (NewMenuVar == 0) {
            NewMenuVar = MenuCount;
          }
      
        if (NewMenuVar == 1)
          {
              OzOled.setCursorXY(0,0);   
              OzOled.printString("   MAIN MENU");  
              OzOled.setCursorXY(0,2);  
              OzOled.printString(" PRESS BUTTON TO ");  
              OzOled.setCursorXY(0,3);  
              OzOled.printString(" TEST COMPONENTS "); 
              //rainbow(20);
          } 
        else if (NewMenuVar == 2)
          {
            showLightSensor();
          }     
        else if (NewMenuVar == 3)
          {
            //showLightSensor();
            OzOled.setCursorXY(0,0);   
            OzOled.printString(" STARTING ");
            OzOled.setCursorXY(0,1); 
            OzOled.printString(" DEMO MODE... ");
            OzOled.setCursorXY(0,2);   
            OzOled.printString(" PRESS RESET ");
            OzOled.setCursorXY(0,3);   
            OzOled.printString(" TO EXIT ");
            delay(3000);
            StartDemoMode();
          }
                  
           else 
              {
               // OnOffBool1 = 0;
              }  

  //delay(100);        
}

///////////////////////////////////////////////////////////////////////////////////////////////////////////////////

void StartDemoMode(){
  int demodelay = 2000;
  int theaterChaseDelay = 100;
  int neoPixelIntensity = 64; // (255 is max, 0 is min)

  OzOled.clearDisplay();

  OzOled.drawBitmap(HudsonAlphaBitmap, 0, 0, 16, 8);

  theaterChase(strip.Color(0, 0, neoPixelIntensity), theaterChaseDelay); // blue
  colorWipe(strip.Color(0, 0, 0), 0);    // Black/off

  OzOled.drawBitmap(UrbanEngineBitmap, 0, 0, 16, 8);

  theaterChase(strip.Color(0, neoPixelIntensity, 0), theaterChaseDelay); // blue
  colorWipe(strip.Color(0, 0, 0), 0);    // Black/off

  OzOled.clearDisplay();
  OzOled.setCursorXY(0,1);   
  OzOled.printString("    PRESENT");
            
  theaterChase(strip.Color(neoPixelIntensity, neoPixelIntensity, neoPixelIntensity), theaterChaseDelay); // white
  colorWipe(strip.Color(0, 0, 0), 0);    // Black/off

  OzOled.drawBitmap(HATCH2020Bitmap, 0, 0, 16, 8);

  theaterChase(strip.Color(0, 0, neoPixelIntensity), theaterChaseDelay); // Blue
  colorWipe(strip.Color(0, 0, 0), 0);    // Black/off

  OzOled.clearDisplay();
  OzOled.setCursorXY(0,1);   
  OzOled.printString("   HACK THIS ");
  OzOled.setCursorXY(0,3);   
  OzOled.printString("   TROPHY!!! ");
            
  theaterChase(strip.Color(neoPixelIntensity, neoPixelIntensity, neoPixelIntensity), theaterChaseDelay); // white
  colorWipe(strip.Color(0, 0, 0), 0);    // Black/off

  goToAwardMenu();

  rainbow(100);
  colorWipe(strip.Color(0, 0, 0), 0);    // Black/off

  DisplayLightSensorForDemo();

  OzOled.clearDisplay();
  OzOled.setCursorXY(0,1);   
  OzOled.printString("   HACK THIS ");
  OzOled.setCursorXY(0,3);   
  OzOled.printString("   TROPHY!!! ");

  rainbowCycle(20); //20
  colorWipe(strip.Color(0, 0, 0), 0);    // Black/off

  theaterChaseRainbow(50); //50
  colorWipe(strip.Color(0, 0, 0), 0);    // Black/off

  //OnOffBool9 = 0;
}

///////////////////////////////////////////////////////////////////////////////////////////////////////////////////
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

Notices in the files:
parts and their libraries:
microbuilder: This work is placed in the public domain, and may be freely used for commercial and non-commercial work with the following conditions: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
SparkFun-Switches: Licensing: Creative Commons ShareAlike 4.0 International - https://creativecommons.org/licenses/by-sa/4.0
